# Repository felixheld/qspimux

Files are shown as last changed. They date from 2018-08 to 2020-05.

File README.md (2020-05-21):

# qspimux - a quad SPI NOR flash multiplexer

For both continious integration systems and initial development of bootloaders and firmware images while being off-site, it is necessary to either replace the commonly used (quad) SPI NOR flash of the system with an expensive SPI flash emulator or attach a programmer to the flash chip and hope the programmer and the device won't interfere.
The latter is usually a bad idea as it might cause damage to both the target and the programmer and at the time of writing this getting a SPI NOR flash emulator is rather expensive; especially if you want to run tests on multiple targets and need one emulator per target for that.

This project takes a different approach and is loosely based on the idea behind lynxis' [spisolator2](https://github.com/lynxis/spisolator2) that is based on [urjaman's spisolator]( https://github.com/urjaman/spisolator).
Here the flash doesn't get emulated, but the access to a real SPI NOR flash chip gets multiplexed between the target and a programmer that also controls the multiplexer. Since today's NOR flashes are quite robust and the programmer should verify the flash contents after writing a new image, I don't expect flash-wearout-related problems to become a major issue. It might however be good idea to count the number of rewrites to be able to replace the flash chip before reaching the number of writes the manufacturer assures the flash to be still good after.

The full hardware design consists of three boards  that are stacked on top of each other:

* **flash-adapter** contains the SPI flash; there are currently adapters for flashes in SOIC8W and SOIC16W packages.
* **qspimux** does the multiplexing of the SPI flash between the target board and the programmer and contains a connector to the programmer. This connector also contains the control signal that selects to which component the SPI flash is connected.
* **qspimux2** is a redesign of **qspimux** that only has components on one side which heavily improves manufacturability.
* **board-adapter** on the embedded system's mainboard. Currently there are board adapters for DIP8, SOIC8W and SOIC16W footprints; the SOIC8W one should also fit on a WSON8 footprint. To improve solderability, the board adapter boards should be manufactured with either 0.6mm or 0.8mm thickness; using the usual 1.6mm might be cheaper, but makes it difficult to properly solder the adapter onto the mainboard.

The **flash-adapter** can be plugged directly onto the **board-adapter** when the **qspimux** isn't needed.

The DIP8 **board-adapter** can be used to plug a SPI flash on a **flash-adapter** board into a programmer with ZIF socket.

**qspimux2-prog** is a programmer designed to work together with **qspimux2**. It supports both 1.8V and 3.3V signal levels and quad SPI mode, can control the qspimux2, provides a low voltage serial and I2C port, 4 potential-free outputs and 4 optocoupler inputs. It is connected to the host via USB.
TODO: add link to firmware repository when the firmware is written.

## how to setup the hardware

* If applicable, remove the flash from the mainboard; usually this works best when using a hot air rework station.
* Solder the board adapter onto the footprint of the SPI flash on the board and then solder a 2x4 socket on the board.
* Solder the flash to the flash adapter and a 2x4 pin header on the bottom of the flash adapter.
* Plug the flash onto the qspimux board. For the 8 pin flash packages pin 1 of the flash must point to the top left, for the 16 pin packages pin 1 must point to the top right.
* Connect the programmer to the programmer header; the upper 2x4 pins of the header have the same pinout as the flashes, one of the lower two pins selects if the flash gets connected to the programmer or the mainboard, the other one can be used to detect from the programmer if the board is powered.
* Plug the qspimux PCB in the socket on the board adapter. Also make sure that you plug the board onto the mainboard in the right orientation; for the 8 pin footprints pin 1 needs to point to the top left, for the 16 pin one pin 1 needs to point to the top right.
* fix the cable(s) to the programmer, so that you don't accidentally rip the qspimux from the mainboard it is connected to.
* Use the qspimux setup :)

If the setup doesn't work as expected, please try to plug the flash adapter directly onto the board adapter and see if that works. Since the boards adapters in the first batch (v1.0) should have been a bit less wide and the diameter of the castellated holes in rather small, soldering the board adapter onto the board might be a bit difficult and the cause of a not correctly working setup.

The two pin footprint on the flash adapter boards are for an optional capacitor near the flash chip. This capacitor is usually not needed, but in the case of a badly designed flash chip power supply on the target mainboard it might help to get the flash chip working reliable.

If you wonder about the weird pin numbering in the schematics: KiCad didn't have symbols/footprints with the right numbering and I just connected everything in the way that the footprints match to the flash pinout.

## design goals and decisions

no emulation:
* since it uses the real flash chip, it doesn't behave differently than the real flash chip, so an unmodified firmware image can be used.
* design not very complex and relatively inexpensive
* downsides: flashing takes some time and flashes are only guaranteed to survive a certain number of erase cycles. Since the guaranteed number of erase cycles is typically 100000, this shouldn't be a real limitation.

minimal interference when the flash is connected to the mainboard:
* analog mux has small propagation delay
* no long cables to the mainboard or the flash chip
* connection to the programmer not connected to flash when it is connected to the board. Monitoring of flash accesses by the mainboard isn't possible with this though

minimize chance of short circuits:
* small board with castellated holes on two edges with a socket soldered on top instead of a pin header with long legs. SOIC8W adappter also works for WSON8
* socket and not a pin header on the board adapter
* only partially solved problem: the small connectors don't have mechanical keying. As a workaround there are flash adapters with added reverse polarity protection

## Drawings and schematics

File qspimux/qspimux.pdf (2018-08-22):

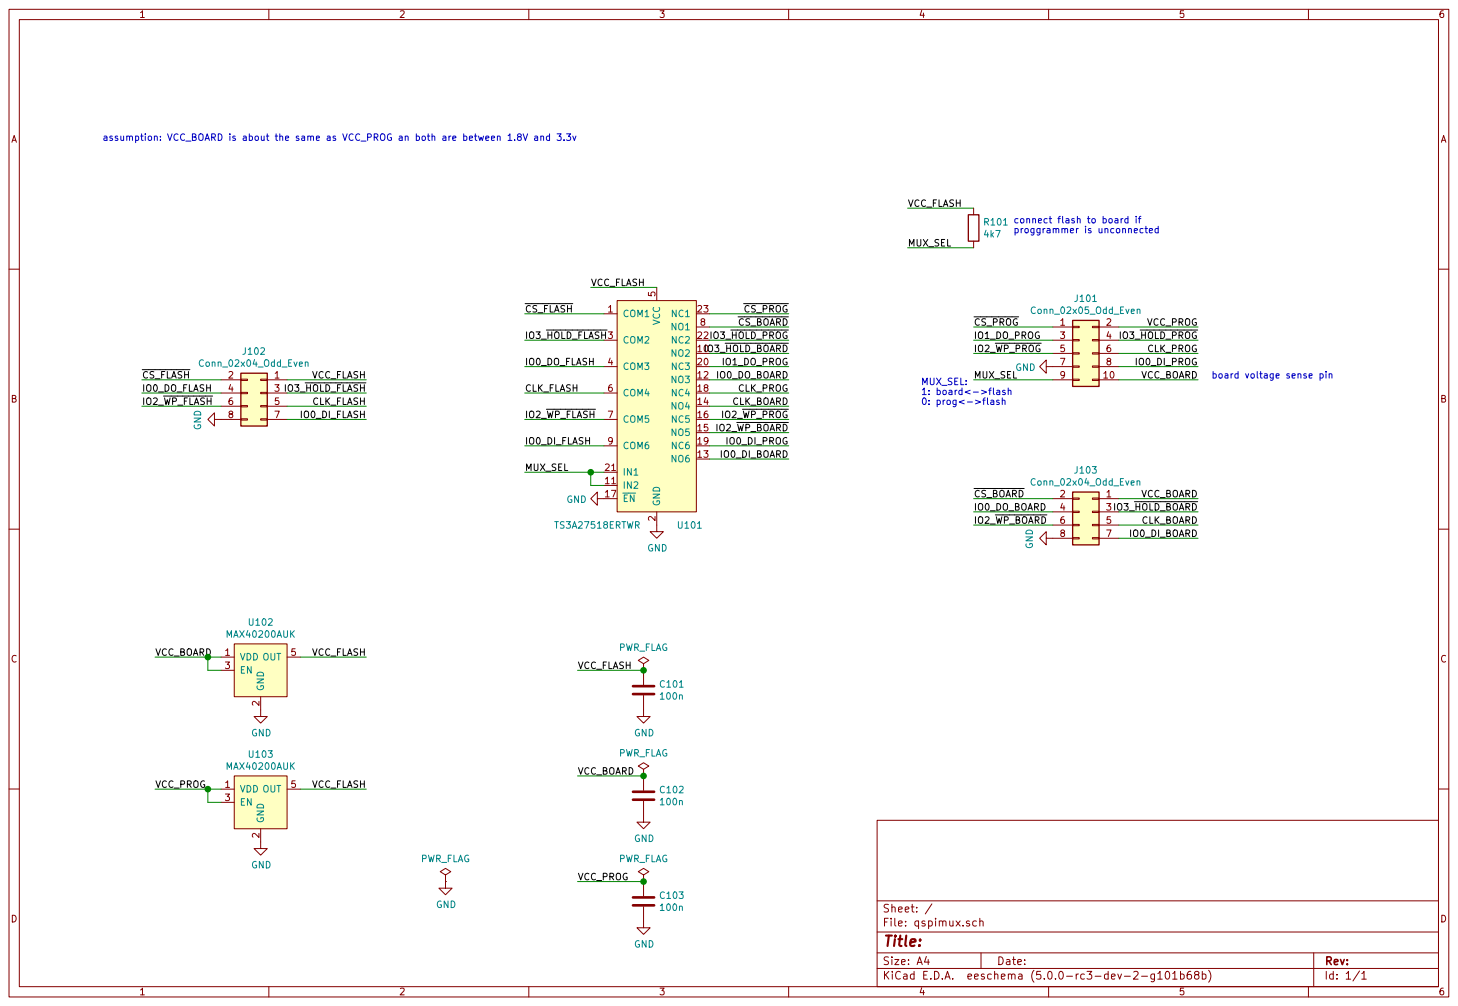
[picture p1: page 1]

connect flash to board if proggrammer is unconnected

File: qspimux.sch Sheet: /
Id: 1/1 Title:

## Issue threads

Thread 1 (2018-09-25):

New SOIC8 board adapter

siro20, 2018-09-25:
The existing SOIC-8 board adapter is difficult to solder. It would be nice to have a smaller PCB and bigger pads below.

felixheld, 2018-09-25:
I'll decrease the width of the PCB, so that you can solder it more easily; I can increase the diameter of the castellated holes only by about 0.1mm though, since I'm rather close to the minimum distance in the pcbway design rules. The diameter of the castellated holes is already below their recommended minimum diameter, but I made sure that they are able to manufacture that. Oh and the boards only have castellated holes without edge plating, because the additional cost for edge plating would have massively increased the price (IIRC by a factor of ~6 for that board).
I'm planning to tweak the board adapter design a bit, but it is constrained by what can be done on a reasonably priced manufacturing process.

felixheld, 2020-08-02:
Ordering a thinner (0.6mm instead of 1.6mm) version of the board adapter improved the aspect ratio of the castellated holes and solved the solderability issue for me.

felixheld, 2021-09-28:
The 0.6mm thin SOIC8W board adapter works much better than the 1.6mm ones, so I'll close this bug, since I also don't see improvements that wouldn't massively increase the manufacturing cost here. Feel free to reopen if the thinner board adapters don't work for you.

Closed 2021-09-28.

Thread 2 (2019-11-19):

Wishlist

APrettyButterfly, 2019-11-19:
Hi,

I just came across your project  since I was looking for some kind of SPI emulator or $something to plug in to my mainboard for booting  from external flash.
Problem is : I suck at soldering (so do probably others ...) and even if I didn't there is always some risk involved when doing that on some "production" mainboard.
However, some boards have a SPI header where you can connect an external SPI chip. There have been also some tools for attaching things to those like  http://shop3.nanobios.cafe24.com/article/Manual/3/24/ or https://www.pcengines.ch/spi1a.htm . The latter one is not really universal while the former looks like it is not available anymore.
Do you see any possibility to kind of merge those with the current hardware of qspimux?
From using a well know search engine I could already find some people making use of qspimux and you seem to also want to sell some of those/setup a crowdfunding campaing.
I think this project would be very interesting for all those Bios modders.  There are also more and more talks/presentations for Bios/Firmware security. qspimux would make it much easier to do analysis and gain visibility on layers where the OS can't reliably look into. There have been holes in SecureBoot and just recently TPMs. The only real way to lock down the Bios is just to write protect it after the initial setup. With some kind of external chip this would also be much easier. Early mainboards had a jumper for write protection. So maybe you could add one too ?
For those boards which don't have such kind of external header maybe some SOIC clip could be added, but I'm not sure if this would work in general for attaching to the current SPI and booting from the external chip. Some board also have  a socketed chip. Maybe there could also be some kind of qspimux hardware module for those ?
I'm not a hardware guy, more like the average end user so I don't know if there is a feasible/economical solution for all of those items on my wishlist. But  (in my biased opinion :D ) I think for a crowd-funding campaign  broadening the potential applications and making it easier for the end user to use your device , is not a bad thing.

felixheld, 2019-11-19:
Hi!

Yeah, the soldering part does have a certain risk of damaging the board; especially when you don't have suitable soldering equipment. With a hot air rework station it's much easier to remove the flash from the board and less likely to rip off some traces from the board.

Using the special connectors on a board should work, but problem is that probably every vendor or at least every OEM having such a connector in their mainboard design will likely have a different pinout and maybe even a different connector type. Making adapters that only work for certain boards shouldn't be too difficult though.

The write protect pin isn't available when the flash is in quad SPI mode; adding a jumper would break the quad mode. Also in order for the write protect pin to have an effect some flashes need to have some protected range registers written by the firmware. Having a flash adapter with a jumper to either connect the #WP pin of the flash to the trace from the board or to ground might be useful. Oh and on modern platforms you can't write-protect the whole flash anyway without breaking functionality, since for example suspend to RAM won't work when the memory controller settings can't be written to some part of the flash.

Using a SOIC clip to connect to the on board flash only works in the case that the board doesn't use the quad SPI mode and doesn't connect the #HOLD pin directly to the flash's power supply, since you have to pull that pin to ground to disable the on-board flash. Directly connecting that pin externally to ground might damage the target board when the pin is directly connected to the supply voltage on the board. If just some pull-up resistor is used, this should be safe, but this is something that has to be verified before connecting a clip to the on-board flash in order to not fry the board and I doubt that everyone will always do that :/ So I'm not sure if it would be a good idea to offer adapter boards for that; documenting the possibility and the conditions for that is probably a good idea though.

I have a board adapter to plug into DIP8 sockets; that adapter needs some rework though, since it uses normal pin headers that don't fit well into the sockets. Looked into that a few days ago but IIRC the connector I thought about using wasn't in stock.

I'm not sure yet if doing a crowdfunding or getting some company to make and sell qspimux2 boards and the adapters would be the better idea. I primarily want the boards to be available, but didn't really get around to figure out how to do that without having to invest too much time or money. The two main things that aren't easy to have manufactured yourself are the SOIC board adapters (need non-standard manufacturing steps for the contacts on the sides) and the qspimux2 itself (small components that can't be easily soldered without stencil, solder paste and hot air or a soldering oven).

But yeah, the project is currently mostly solving the automatic reflashing without interfering with the board problem I had. I'm not sure if there will be a significant improvement in user-friendliness over the current state, since most possible improvements I thought of are either very specific to some boards or use cases or don't work for some use cases I have.

Hope that helps; if you have any more questions or suggestions, just ask :)

I wanted to write some more documentation and also explain some design decisions, but didn't really get around to do that yet.

APrettyButterfly, 2019-11-19:
Thanks for the elaborate reply :)
Yeah from the first link you can already see that you require different pinouts for different vendors.
Regarding the WP pin, sure you would loose some functionality as in most cases where you increase the security. I can only speak for myself but I guess suspend to RAM is mostly used for notebooks and not your average desktop or server system. Or is there anything else which would break?

felixheld, 2019-11-21:
Just had a look in the datasheet of the W25Q64FV spi flash (if you're interested in that topic, I'd suggest to read the corresponding sections) and there the #WP pin will only get used for write protection when a certain bit in the status register is set. And then it'll only protect the status register containing some write protection and security register lock bits. So the flash chip needs to be configured first to do what you expect when you pull the #WP pin low; the "write protect" name might be a bit misleading here, since it doesn't causes all flash writes to be ignored without further configuration. The same functionality can also be done from firmware, but needs to be reapplied after the flash lost power. IIRC some platforms did that, but forgot to send the lock command after a suspend-resume cycle...
If you write-protect the whole chip, apart from suspend to RAM I'd expect that some of the embedded microprocessors in the platform might get unhappy when they can't write to their parts of the flash chip. Haven't tried fully write-protecting a flash to see what breaks, but at least on some older Intel platform I looked at the management engine writes to a part of the flash. But yeah, write-protecting things some part of the firmware expects to be writable might break things in possibly non-obvious ways. I don't want to discourage you trying that, but you should be aware that you might hit bugs, features and undefined behavior there ;)

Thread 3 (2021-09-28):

look into using TCA9416 as I2C level shifter for qspimux2-prog

felixheld, 2021-09-28:
Haven't verified if the dual-MOSFET used in the current design works 100% reliable when the I2C bus is running at 1.8V. If not, the TCA9416 or a similar device from the same family might be worth a look.

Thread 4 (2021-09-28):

improve SOIC8W flash adapter layout

felixheld, 2021-09-28:
The two rows of pads are a little bit too far away to easily solder a WSON8 chip onto it. In the current design, I tried to have enough space between those to avoid shorts to the ground pad of the WSON8 package, but turns out that now the two rows are so far apart that it's a bit tricky to properly solder the WSON8 package onto it.

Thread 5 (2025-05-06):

Chip not detected by Meteor Lake ASROCK NUC-BOX-155H

filipleple, 2025-05-06:
The platform acts as if there were no flash chip when connecting it via qspimux and driving the `MUX_SEL` pin with the chip's VCC (3.3V). That is, no LED's, nothing observable happens when plugging in DC and pushing the power button.

The mux mechanism seems to work for the programmer - it does or does not detect the flash chip depending on the `MUX_SEL` state.

I noticed the solder pads for a capacitor near the flash chip, as well as the note in the documentation. Could you clarify what capacitance has been tested or recommend an approximate value to order?

felixheld, 2025-05-06:
Hm, good question why this doesn't work on that board. Have you checked all the solder connections and have you tested if the same qspimux works with another board? My guess would be bad solder connection; especially if you're using the 1.6mm board adapters; the much thinner ones are significantly easier to solder.
On the capacitor near the flash chip: I'd just use 100nF which is sort-of the common value to use unless there's a good reason to use other values.

felixheld, 2025-05-06:
To test the soldering connection, I'd suggest that you try plugging the board with the SPI flash directly into the board adapter without the qspimux in between. If that doesn't work, it's likely some bad solder connection; if it works in that case, the case with qspimux will need more debugging.
I assume that you already checked if the qspimux is connected the right way around onto the board adapter, right?

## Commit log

2018-07-15 add .gitignore for KiCad project
2018-08-14 add initial qspimux schematics and layout
    [qspimux.kicad_pcb, qspimux.sch]
2018-08-16 add SOIC8 and SOIC16 flash adapter designs
    [flash-adapter-16.kicad_pcb, flash-adapter-16.sch, flash-adapter-8.kicad_pcb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]
2018-08-16 fix mirrored footprints in qspimux design
    [qspimux.kicad_pcb, qspimux.sch]
2018-08-16 add DIP8 board adapter design
    [board-adapter-DIP8.kicad_pcb, board-adapter-DIP8.sch]
2018-08-16 add SOIC8W board adapter
    TODO: verify if edges will get plated as expected
    [board-adapter-SOIC8W.kicad_pcb, board-adapter-SOIC8W.sch]
2018-08-16 rename flash adapters from pin count to package type
    [flash-adapter-SOIC16.kicad_pcb, flash-adapter-SOIC16.sch, flash-adapter-SOIC8W.kicad_pcb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]
2018-08-18 add SOIC16 board adapter
    [board-adapter-SOIC16.kicad_pcb, board-adapter-SOIC16.sch]
2018-08-18 fix SOIC8W adapter pin row pitch
    [board-adapter-SOIC8W.kicad_pcb]
2018-08-18 slightly optimize routing
    [qspimux.kicad_pcb]
2018-08-18 fix power supply circuitry
    The old version was lacking reverse current protection on Q101.
    [qspimux.kicad_pcb, qspimux.sch]
2018-08-18 move layout-related TODO to layout file
    [qspimux.kicad_pcb, qspimux.sch]
2018-08-20 increase trace width
    [board-adapter-DIP8.kicad_pcb, board-adapter-SOIC16.kicad_pcb, board-adapter-SOIC8W.kicad_pcb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]
2018-08-22 remove pin 1 markers from wrong position
    [board-adapter-DIP8.kicad_pcb, board-adapter-SOIC16.kicad_pcb, board-adapter-SOIC8W.kicad_pcb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]
2018-08-22 fix footprint of TS3A27518ERTWR
    [qspimux.kicad_pcb, qspimux.sch]
2018-08-22 qspimux: add fiducials
    [qspimux.kicad_pcb]
2018-08-22 board-adapter-DIP8: fix slightly wrong pitch
    [board-adapter-DIP8.kicad_pcb]
2018-08-22 add pdf version of qspimux schematics
2018-08-22 qspimux: fix fiducial pad that was misaligned with its footprint
    [qspimux.kicad_pcb]
2018-08-22 update pad to mask clearance
    [board-adapter-DIP8.kicad_pcb, board-adapter-SOIC16.kicad_pcb, board-adapter-SOIC8W.kicad_pcb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]
2018-08-22 set gerber export path and format
    [board-adapter-DIP8.kicad_pcb, board-adapter-SOIC16.kicad_pcb, board-adapter-SOIC8W.kicad_pcb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]
2018-08-23 flash-adapter-SOIC8W: move vias from underneath the chip
    [flash-adapter-SOIC8W.kicad_pcb]
2018-08-27 change geometry of castellated holes to avoid edge plating fee
    [board-adapter-SOIC16.kicad_pcb, board-adapter-SOIC8W.kicad_pcb]
2018-08-27 add zip archives of the gerber files that got ordered
    This is mainly for your convenience, so that you can order the boards yourself.
    The SOIC board adapters need castellated holes that some manufacturers can make
    for a slight surcharge; the rest can be made on a 2 layer 6mil/6mil with 0.3mm
    vias process.
2018-08-27 add gerber folder to .gitignore
    The subfolders of the gerber folder contain the generated gerber files that can
    be generated from the board files. With every release the archives in the
    gerber-release folder get updated, so I don't see much use of pushing the
    contents of the gerber folder.
2018-09-25 add check for bad solder connection of board adapter to README
2018-10-05 README.md: add comment about capacitor footprint on flash adapter
2019-03-11 add non-default QFN footprint to project
2019-03-11 qspimux: update project to use newly included symbols/footprints
    [qspimux.kicad_pcb, qspimux.sch]
2019-03-18 add connector footprints for qspimux rev2
2019-03-18 add qspimux rev2 schematics
    [qspimux.sch]
2019-03-18 add qspimux rev2 layout
    [qspimux.kicad_pcb]
2019-03-19 correct gerber output directory for qspimux2
    [qspimux.kicad_pcb]
2019-03-19 fix wrong signal name
    the connection was right, but the name had an off-by-one
    [qspimux.kicad_pcb, qspimux.sch]
2019-03-19 qspimux: fix remaining net name bug
    [qspimux.kicad_pcb, qspimux.sch]
2019-03-19 qspimux2: rename project files and fix net name bugs
    [qspimux2.kicad_pcb, qspimux2.sch]
2019-03-19 add pin header adapter for qspimux2
    [qspimux2-pinheader-adapter.kicad_pcb, qspimux2-pinheader-adapter.sch]
2019-03-28 qspimux2: slighty optimize board layout
    [qspimux2.kicad_pcb]
2019-03-28 qspimux2-pinheader-adapter: add gerber output directory
    [qspimux2-pinheader-adapter.kicad_pcb]
2019-03-29 qspimux2: rename connectors to match the actual part numbers
    [qspimux2.kicad_pcb, qspimux2.sch]
2019-04-17 qspimux2: add note on reversed pin numbers on ffc connector
    [qspimux2.sch]
2019-06-06 flash-adapter: add variants with reverse polarity protection
    accidentially plugging in the module rotated by 180 degrees shouldn't fry the flash on these boards
    [flash-adapter-reverse-polarity-protected-SOIC16.kicad_pcb, flash-adapter-reverse-polarity-protected-SOIC16.sch, flash-adapter-reverse-polarity-protected-SOIC8W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]
2019-11-16 improve qspimux2 manufacturability
    move the vias to the ground planes a bit away from the components
    [qspimux2-pinheader-adapter.kicad_pcb, qspimux2.kicad_pcb]
2019-12-07 add qspimux2-prog board
    initial commit for this sub-project
    [i2c.sch, led.sch, opto_in.sch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]
2019-12-08 add schematics backup files to gitignore
2019-12-08 qspimux2-prog: add gerber output file directory
    [qspimux2-prog.kicad_pcb]
2019-12-08 qspimux2-prog: add pull down resistors to enable and select inputs of vdd regulator
    [power.sch, qspimux2-prog.kicad_pcb]
2019-12-08 qspimux2-prog: unhide layers 2 and 3 and regenerate polygons
    [qspimux2-prog.kicad_pcb]
2019-12-13 qspimux2-prog: add values for ldo feedback network
    [power.sch, qspimux2-prog.kicad_pcb]
2019-12-26 add a few missing capacitors and do some slight layout optimizations
    add two missing capacitors on the supply rails of the microcontroller
    add capacitor to vtarget monitoringto get a low pass
    [qspi_buffer.sch, qspimux2-prog.kicad_pcb, qspimux2-prog.sch]
2020-03-22 gerber-release: add qspimux2 and qspimux2-pinheader-adapter
2020-03-22 gerber-release: add flash adapters with reverse polarity protection
2020-05-21 README.md: add note about board adapter thickness
2020-11-22 add new improved version of the DIP8 adapter board
    The revision 2 of the DIP8 adapter can be used as board adapter or flash
    adapter. Since no boards have been ordered yet, it's still untested.
    [board-adapter-DIP8-rev2.kicad_pcb, board-adapter-DIP8-rev2.kicad_sch]
